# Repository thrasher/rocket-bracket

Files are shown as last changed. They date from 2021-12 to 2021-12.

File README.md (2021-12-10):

# Model Rocket Wall Mount

## Summary

Model rockets are fragile and storing them safely is challenging.
Making them visually-accessible via display helps to keep interest and curiosity in rocketry.

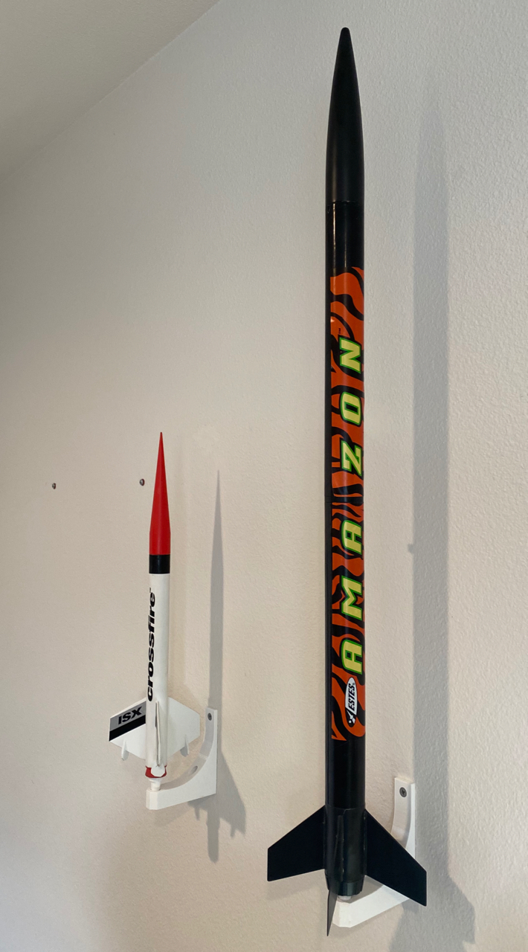
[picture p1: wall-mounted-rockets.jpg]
Wall mounted rockets


This project provides the 3D models for a bracket allowing storage and display of model rockets.
Since model rockets can take several newtons of force through their engine mounts - it is assumed that this is the most durable part of the rocket to use for mounting.
The wall bracket mounts the rocket vertically on the wall by way of an engine-blank.

Included parts for mounting:
1. [Wall bracket](rocket-wall_bracket.stl)
1. [Engine blank](rocket-engine_blank.stl)

Required parts to complete:
1. 2x small drywall screws (or similar) for each bracket

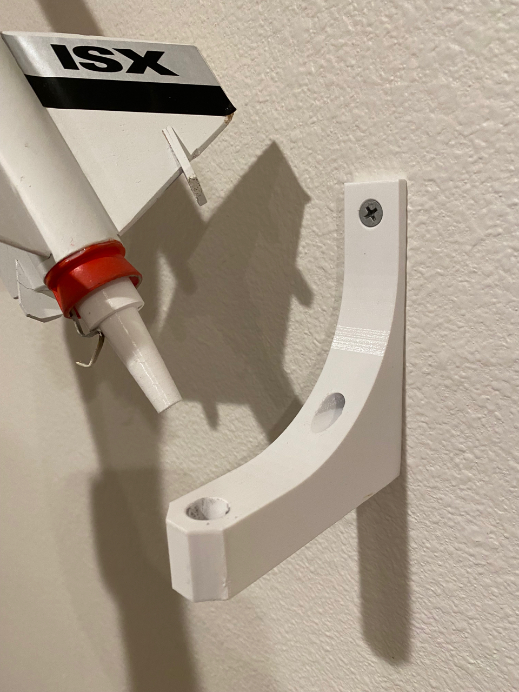
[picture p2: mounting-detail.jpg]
parts detail


## Print Settings

Print the engine blank in draft mode, as it's asthetics are not required to hold the rockets, and the thicker extrusion will make the part somewhat stronger and faster printing.
Print the wall braket, laying on it's side, with 0.15 to 0.20 mm layer height for asthetic reasons, ~15% infill.

Use PLA or PETG. Note that PLA may give better performance with overhangs, obviating the need for supports. PETG does require supports.

Rockets weighing more than 2 lbs may need different settings.

## Post-Printing Installation

Install on the wall using simple drywall screws. I used 1.25" silver screws. Don't over-tighten them - they should just be barley "firm".
Consider spacing the brackets 6 inches or more apart on the wall to prevent neighboring rocket fins from touching.

## How I Designed This

OpenSCAD and a pair of calipers for measuring the fleet of rockets.

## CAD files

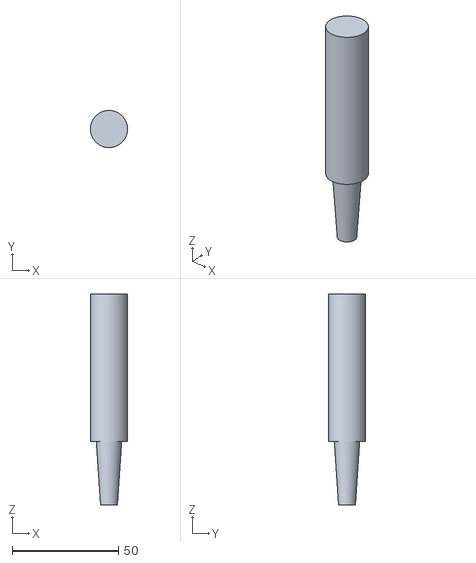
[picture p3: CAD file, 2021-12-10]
rocket-engine_blank.stl
17.5 x 17.5 x 99.5

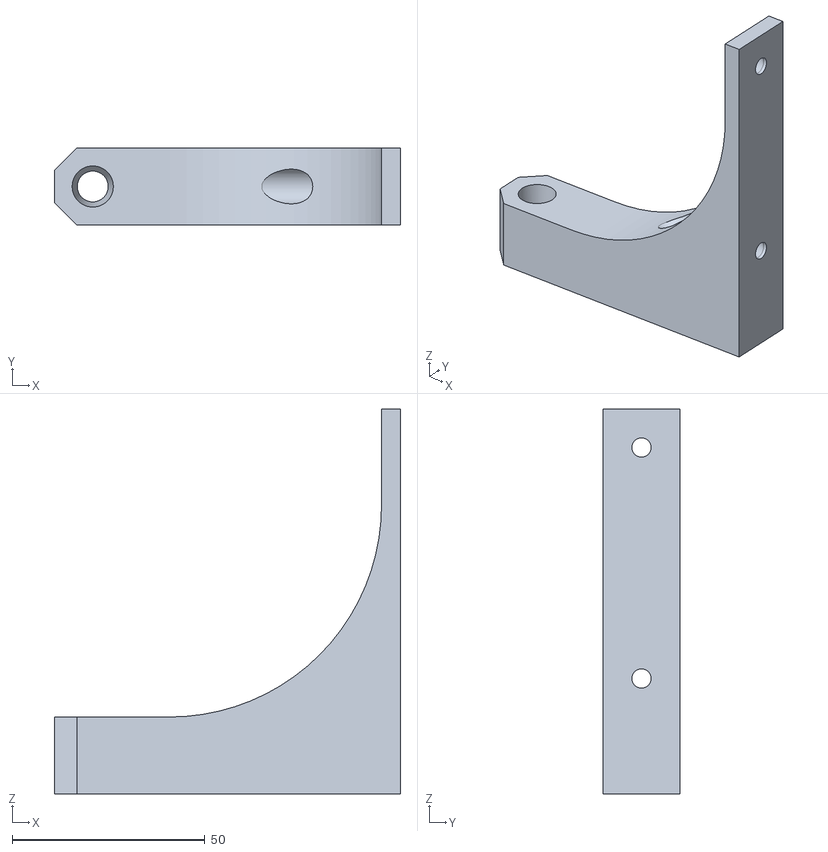
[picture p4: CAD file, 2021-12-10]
rocket-wall_bracket.stl
90.0 x 20.0 x 100.0

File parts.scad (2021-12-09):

// all dimensions in millimeters

// see: https://en.wikibooks.org/wiki/OpenSCAD_User_Manual/Other_Language_Features#$fa,_$fs_and_$fn
$fs = 2; // minimum size of a circle fragment, default=2, min=0.01
$fa = 15; // a circle has fragments = 360 divided by this number, default=12, min=0.01
$fn = $preview ? 24 : 80; // number of fragments in a circle, when non-zero $fs and $fa are ignored, default=0
chamfer_extrude = $preview ? 4 : 12;

use<scad-utils/morphology.scad>

// parameterized dimensions and measurements
WALL_TO_CENTERLINE = 80; // clearence from wall to centerline of rocket for fins
ENGINE_DIA = 17.5; //17.5 - 17.8 as measured
ENGINE_HT = 69.5; // 69.75 as measured
ENGINE_EXHAUST_DIA = 12.0; // 12.6 as measured
WALLPLATE_THICKNESS = 5;
WALLPLATE_W = 20;
WALLPLATE_H = 100;
MOUNT_OFFSET = 30; // leave 15mm clearence below engine

module engine() {
	color("brown")
	cylinder(d = ENGINE_DIA, h = ENGINE_HT);
}

module engine_blank() {
	cylinder(d1 = 8, d2 = ENGINE_EXHAUST_DIA, h = MOUNT_OFFSET);
	translate([0,0,MOUNT_OFFSET])
	engine();
}

module wall_bracket() {
	// translate([-WALL_TO_CENTERLINE/2, 0, 5])
	// cube([WALL_TO_CENTERLINE, WALLPLATE_W, 10], center = true);

	// translate([-WALL_TO_CENTERLINE + WALLPLATE_THICKNESS/2, 0, WALLPLATE_H/2])
	// cube([WALLPLATE_THICKNESS, WALLPLATE_W, WALLPLATE_H], center = true);
	difference() {
		union() {
			arm();
			rotate([0,0,45/2])
			cylinder(d = WALLPLATE_W / cos(45/2), h = WALLPLATE_W, $fn = 8);
		}
		translate([0,0,-.1])
		engine_blank();

		// screw holes
		translate([WALL_TO_CENTERLINE - WALLPLATE_THICKNESS, 0, WALLPLATE_W*1.5])
		rotate([0, -90, 0])
		drywall_screw();
		translate([WALL_TO_CENTERLINE - WALLPLATE_THICKNESS, 0, WALLPLATE_H - WALLPLATE_W/2])
		rotate([0, -90, 0])
		drywall_screw();
	}
}

module arm() {
	rotate([90, 0, 0])
	linear_extrude(height = WALLPLATE_W, center = true)
	difference() {
		fillet(r = WALL_TO_CENTERLINE - WALLPLATE_THICKNESS - WALLPLATE_W)
		bracket_2d();
		// translate([WALLPLATE_W/2, WALLPLATE_W/2])
		// circle(d = WALLPLATE_W/2);
		// translate([WALLPLATE_W/2 * 3, WALLPLATE_W/2])
		// circle(d = WALLPLATE_W/2 * 1.2);
	}
}

module bracket_2d() {
	polygon([
		[0,0],
		[WALL_TO_CENTERLINE, 0],
		[WALL_TO_CENTERLINE, WALLPLATE_H],
		[WALL_TO_CENTERLINE - WALLPLATE_THICKNESS, WALLPLATE_H],
		[WALL_TO_CENTERLINE - WALLPLATE_THICKNESS, WALLPLATE_W],
		[0, WALLPLATE_W]
	]);
}

// screw hole
module screw_hole(head_dia, body_dia) {
    depth = 200;

    CONE = (head_dia - body_dia);

    // head shaft
    translate([0, 0, -0.01])
    cylinder(d = head_dia, h = depth);

    // thread shaft
    translate([0, 0, -depth - CONE])
    cylinder(d = body_dia, h = depth+ 0.01);

    // cone for drywall screws
    translate([0, 0, -CONE])
    cylinder(d2 = head_dia, d1 = body_dia, h = CONE);
}

// drywall screw
module drywall_screw(screw_head_dia = 9, screw_body_dia = 5) {
    screw_hole(screw_head_dia, screw_body_dia);
}



// #####################################################

// move parts depending on single view (rendering) or group view (all parts)
module render(part, location, named) {
	if (part == "all" || part == named) {
		MOVE = (part != "all") ?  [0, 0, 0] : location;
		translate(MOVE) children();
	}
	// echo(parent_module(0));
}

PART = "all";
echo(str("render ", PART));
render(PART, [0, 0, 0], "wall_bracket") wall_bracket();
render(PART, [0, 0, 0], "engine_blank") engine_blank();

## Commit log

2021-12-09 created model rocket wall bracket for display and storage
    [parts.scad]
2021-12-09 added example image of mounted rockets
2021-12-10 added STLs from ./render
    [rocket-engine_blank.stl, rocket-wall_bracket.stl]
